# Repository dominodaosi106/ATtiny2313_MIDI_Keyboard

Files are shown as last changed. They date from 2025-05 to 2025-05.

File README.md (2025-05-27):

# ATtiny2313_MIDI_Keyboard
# MIDIコントローラ基板 取扱説明書(ver1用）

## 概要
このMIDIコントローラ基板は、ATtiny2313Aマイクロコントローラを搭載し、MIDI信号を送信して楽器やソフトウェアを制御するためのデバイスです。以下の機能を提供します：
- 12個のノートボタン（C, C#, D, D#, E, F, F#, G, G#, A, A#, B）による音階の発音
- MIDIチャンネル選択（1～16）
- オクターブシフト機能（-5～+3オクターブ）
- プログラムチェンジ（ピアノ、オルゴール、矩形波、ベース+リード）
- MIDIチャンネル10でのオクターブシフトロック機能

電源を入れると、初期設定に基づいてMIDIチャンネルと基準ノートが設定され、ボタン操作で音を鳴らしたり設定を変更したりできます。

## 操作方法

### 1. 基本操作
- **ノートボタン（C, C#, D, D#, E, F, F#, G, G#, A, A#, B）**：
  - 押す：対応する音階をMIDI信号として発音（ベロシティ127）。
  - 離す：発音開始時の音階を停止。
  - 例：Cボタンを押してC4が鳴り、オクターブシフト後に離すとC4が停止。
- **オクターブシフト（UP/DOWNボタン）**：
  - **短押し（200ms未満）**：押すと即時にオクターブが上下し、離してもシフトを維持。
  - **長押し（200ms以上）**：押すと即時にオクターブが上下し、離すと元のオクターブに戻る。
  - 範囲：-5～+3オクターブ（例：C4→C-1～C7）。
- **ファンクションキー（UP+DOWN同時押し）**：
  - UPとDOWNボタンを同時に押すと、ファンクションキーモードに移行。
  - 他のボタン（C#, D#, F#, A#, C, D, A, B）を押して各種設定を変更。
  - どちらかのボタンを離すと通常モードに戻る。

### 2. ファンクションキーモードでの操作
ファンクションキーモード（UP+DOWN同時押し）で以下の操作が可能です：
- **MIDIチャンネル変更**：
  - **C#**：MIDIチャンネル1（基準ノート：C4）に設定。
  - **D#**：MIDIチャンネル10に設定（基準ノートは現在の値を保持）。
  - **F#**：MIDIチャンネルを1つ下げる（1～16、基準ノートは保持）。
  - **A#**：MIDIチャンネルを1つ上げる（1～16、基準ノートは保持）。
- **プログラムチェンジ**：
  - **C**：プログラム1（ピアノ）に変更。
  - **D**：プログラム10（オルゴール）に変更。
  - **A**：プログラム88（ベース+リード）に変更。
  - **B**：プログラム81（矩形波）に変更。

### 3. 初期設定
- **MIDIチャンネルと基準ノート**：
  - 起動時のCHピンの状態で初期設定：
    - CHピンがLOW：MIDIチャンネル1、基準ノートC4（60）。
    - CHピンがHIGH：MIDIチャンネル10、基準ノートC2（36）。
- **オクターブシフト**：
  - 初期値は0（基準ノートそのまま）。
  - MIDIチャンネル10でMODEピンがHIGHの場合、オクターブシフトは無効（常に0）。

### 4. 注意事項
- **オクターブシフト中の発音**：
  - ノートボタンを押している間にオクターブシフトしても、発音中の音は継続。
  - ノートボタンを離すと、押した時点の音階（例：C4）が停止。
  - 新たに押したノートは現在のオクターブシフトを反映（例：C5）。
- **MIDIチャンネル変更**：
  - CH1からCH10に変更しても、現在の基準ノート（例：C4やC6）が保持される。
  - CH1への変更（C#）では基準ノートがC4にリセット。
- **MODEピン（MIDIチャンネル10）**：
  - MODEピンがHIGHの場合、オクターブシフトが無効化され、基準ノート（C2など）で固定。
- **デバウンス**：
  - ボタン操作は10msのデバウンス処理済み。素早い連打でも安定動作。
- **電源**：
  - 電源投入後、CHピンの状態を即座に読み込み。
  - MIDI機器に正しく接続してください（MIDI OUT端子を使用）。

### 5. トラブルシューティング
- **音が出ない**：
  - MIDIケーブルが正しく接続されているか確認。
  - MIDIチャンネルが受信機器と一致しているか確認（C#, D#, F#, A#で変更）。
  - プログラムチェンジが適切か確認（C, D, A, Bで変更）。
- **オクターブシフトが効かない**：
  - MIDIチャンネル10でMODEピンがHIGHでないか確認（HIGHでシフト無効）。
  - UP/DOWNボタンの短押し/長押しを試す。
- **意図しない音階が鳴る**：
  - 現在の基準ノートとオクターブシフトを確認（CH1: C4ベース、CH10: C2ベース）。
  - ファンクションキー+C#でCH1（C4）にリセット可能。

## 仕様
- **マイクロコントローラ**：ATtiny2313A（内蔵1MHzクロック）
- **ビルド環境**：Atmel Studio 7 (Version: 7.0.129)
- **MIDIボーレート**：31,250bps（標準）
- **電源**：5V（VCC-GND間）
- **ボタン**：12ノートボタン、2シフトボタン（UP/DOWN）、2設定ピン（CH, MODE）

---

ご不明点やサポートが必要な場合は、開発者にご連絡ください。

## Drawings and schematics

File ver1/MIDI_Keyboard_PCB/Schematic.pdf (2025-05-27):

GND | GND ⁺⁵V | +5V

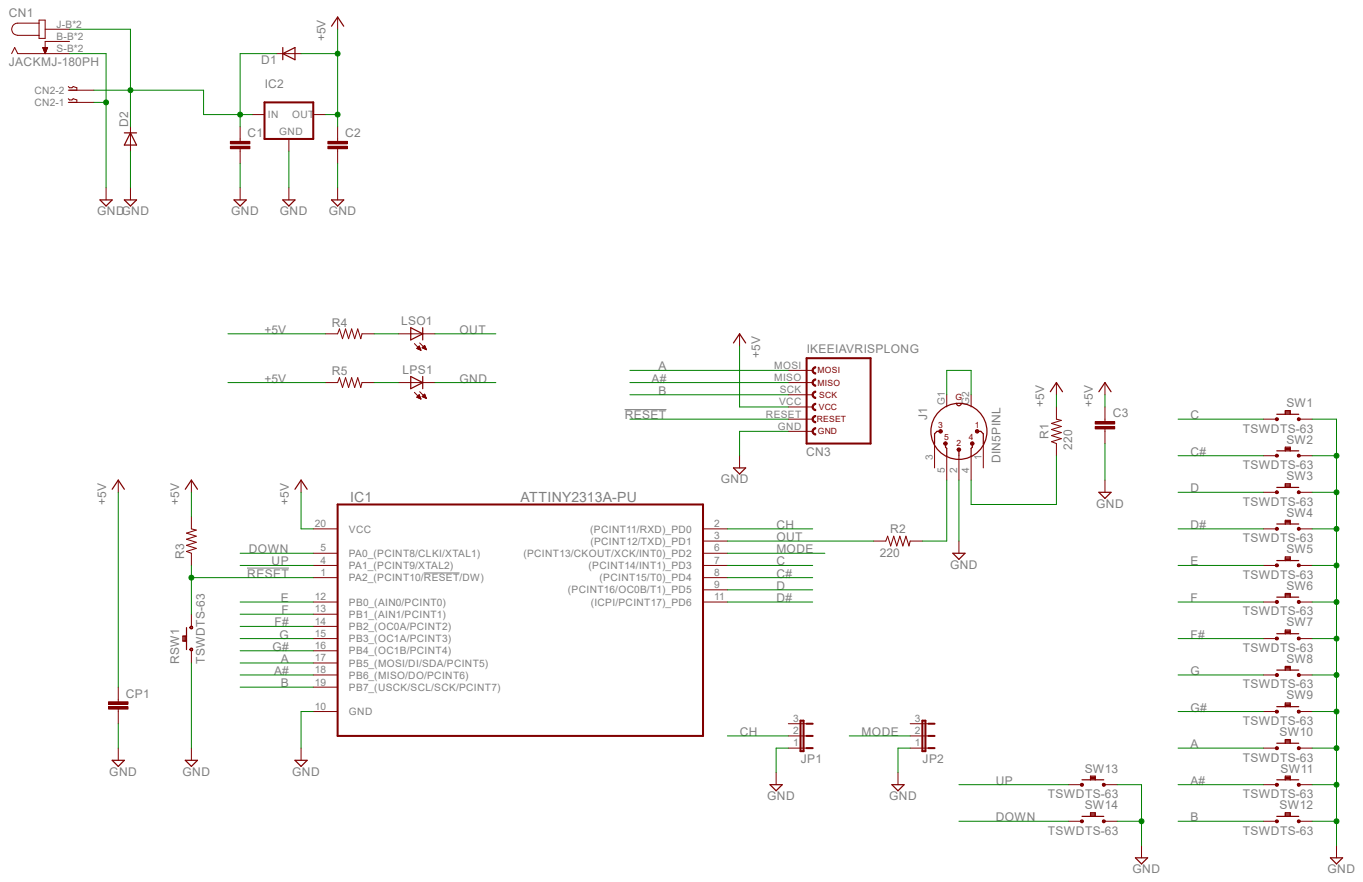
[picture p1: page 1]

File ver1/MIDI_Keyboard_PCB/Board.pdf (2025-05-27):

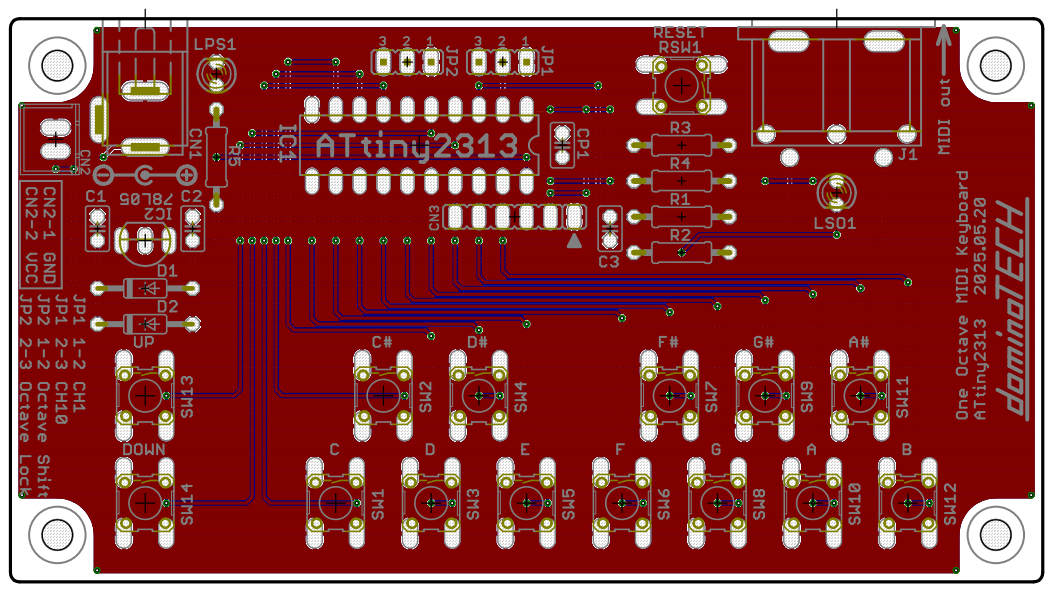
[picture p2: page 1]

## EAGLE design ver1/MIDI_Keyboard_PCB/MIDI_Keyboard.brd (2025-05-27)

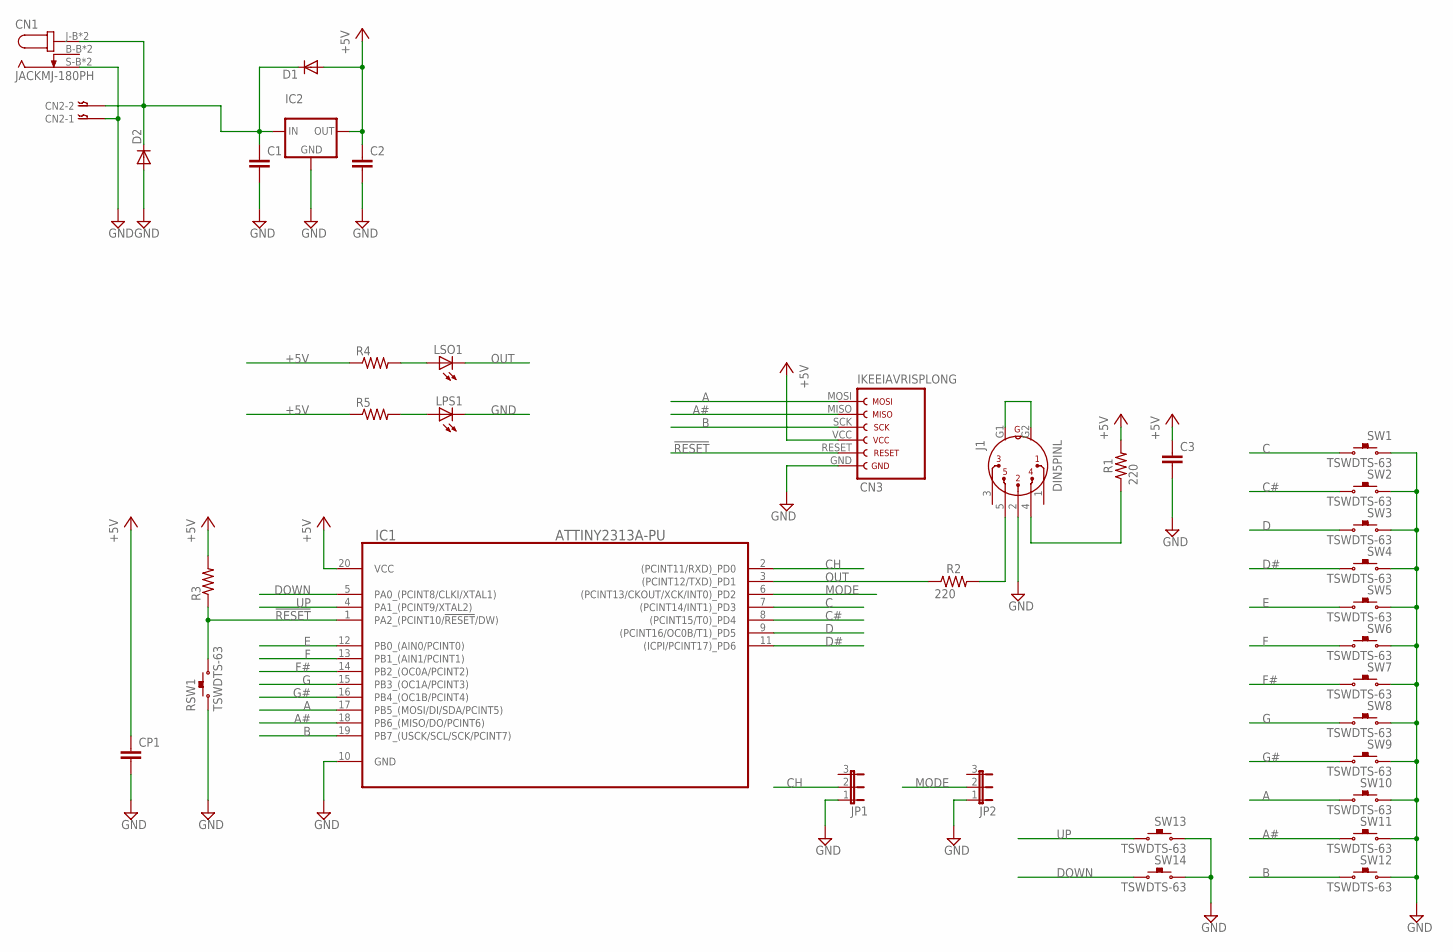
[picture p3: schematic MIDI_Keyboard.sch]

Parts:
C1, C2, C3: C-EU025-025X050; C025-025X050
CN1: JACKMJ-180PH; MJ-179PH
CN2: B2B-XH-A
CN3: IKEEIAVRISPLONG; IKEEIAVRISP
CP1: C-EU025-025X050; C025-025X050
D1, D2: 1N4148DO35-10R; DO35-10R
IC1: ATTINY2313A-PU; DIP254P762X533-20
IC2: 78LXXL; TO92LINE
J1: DIN5PINL
JP1, JP2: JP2E; JP2
LPS1: LED3MM
LSO1: LED3MM
R1, R2: 220; 0207/10
R3, R4, R5: R-US_0207/10; 0207/10
RSW1: TSWDTS-63; DTS-63
SW1, SW2, SW3, SW4, SW5, SW6, SW7, SW8, SW9, SW10, SW11, SW12, SW13, SW14: TSWDTS-63; DTS-63

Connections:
!RESET: CN3.RESET, IC1.1 (PA2_(PCINT10/!RESET!/DW)), R3.1, RSW1.1, RSW1.2 (1)
+5V: C2.1, C3.1, CN3.VCC, CP1.1, D1.A, IC1.20 (VCC), IC2.1 (OUT), R1.2, R3.2, R4.1, R5.1
A: CN3.MOSI, IC1.17 (PB5_(MOSI/DI/SDA/PCINT5)), SW10.1, SW10.2 (1)
A#: CN3.MISO, IC1.18 (PB6_(MISO/DO/PCINT6)), SW11.1, SW11.2 (1)
B: CN3.SCK, IC1.19 (PB7_(USCK/SCL/SCK/PCINT7)), SW12.1, SW12.2 (1)
C: IC1.7 ((PCINT14/INT1)_PD3), SW1.1, SW1.2 (1)
C#: IC1.8 ((PCINT15/T0)_PD4), SW2.1, SW2.2 (1)
CH: IC1.2 ((PCINT11/RXD)_PD0), JP1.2
D: IC1.9 ((PCINT16/OC0B/T1)_PD5), SW3.1, SW3.2 (1)
D#: IC1.11 ((ICPI/PCINT17)_PD6), SW4.1, SW4.2 (1)
DOWN: IC1.5 (PA0_(PCINT8/CLKI/XTAL1)), SW14.1, SW14.2 (1)
E: IC1.12 (PB0_(AIN0/PCINT0)), SW5.1, SW5.2 (1)
F: IC1.13 (PB1_(AIN1/PCINT1)), SW6.1, SW6.2 (1)
F#: IC1.14 (PB2_(OC0A/PCINT2)), SW7.1, SW7.2 (1)
G: IC1.15 (PB3_(OC1A/PCINT3)), SW8.1, SW8.2 (1)
G#: IC1.16 (PB4_(OC1B/PCINT4)), SW9.1, SW9.2 (1)
GND: C1.2, C2.2, C3.2, CN1.S-B (1), CN1.S-T (1), CN2.1, CN3.GND, CP1.2, D2.A, IC1.10 (GND), IC2.2 (GND), J1.2, JP1.1, JP2.1, LPS1.K (C), RSW1.3 (2), RSW1.4 (2), SW1.3 (2), SW1.4 (2), SW2.3 (2), SW2.4 (2), SW3.3 (2), SW3.4 (2), SW4.3 (2), SW4.4 (2), SW5.3 (2), SW5.4 (2), SW6.3 (2), SW6.4 (2), SW7.3 (2), SW7.4 (2), SW8.3 (2), SW8.4 (2), SW9.3 (2), SW9.4 (2), SW10.3 (2), SW10.4 (2), SW11.3 (2), SW11.4 (2), SW12.3 (2), SW12.4 (2), SW13.3 (2), SW13.4 (2), SW14.3 (2), SW14.4 (2)
MODE: IC1.6 ((PCINT13/CKOUT/XCK/INT0)_PD2), JP2.2
unnamed: J1.4, R1.1
unnamed: J1.5, R2.2
unnamed: J1.G1, J1.G2
unnamed: LSO1.A, R4.2
unnamed: LPS1.A, R5.2
unnamed: C1.1, CN1.J-B (3), CN1.J-T (3), CN2.2, D1.C, D2.C, IC2.3 (IN)
OUT: IC1.3 ((PCINT12/TXD)_PD1), LSO1.K (C), R2.1
UP: IC1.4 (PA1_(PCINT9/XTAL2)), SW13.1, SW13.2 (1)

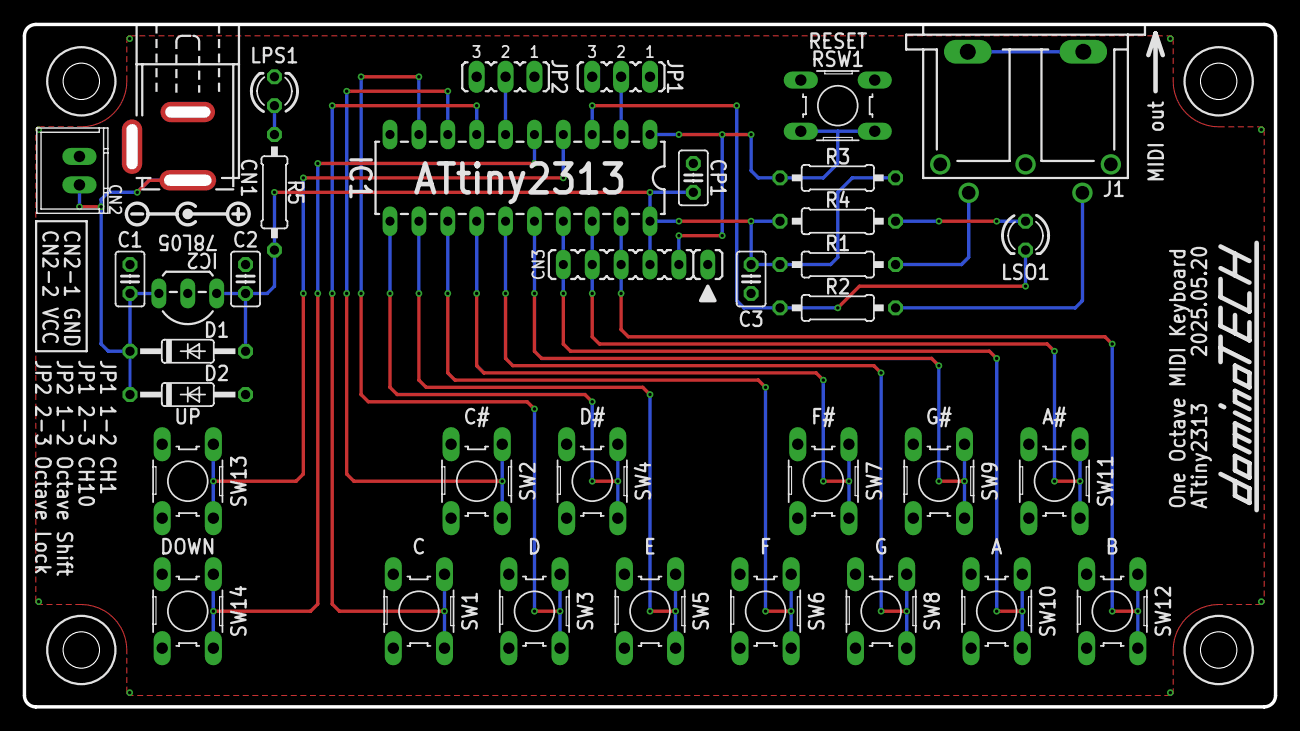
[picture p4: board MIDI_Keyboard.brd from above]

Board: 2 copper layers, 110.0 x 60.0 mm, 36 parts (0 on the bottom side), 26 nets.

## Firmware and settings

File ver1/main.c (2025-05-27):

/*
 * 【ポート対応】 ATtiny2313A
 * x: 存在しない, -: 空き
 * bit       7     6     5     4     3     2     1     0
 * portA     x     x     x     x     x     x     UP    DOWN
 * portB     B     A#    A     G#    G     F#    F     E
 * portD     x     D#    D     C#    C     MODE  MIDI  CH
 *
 * 【ATtiny2313Aピンマッピング】
 *   (RESET) PA2 |1       20| VCC
 *     (CH) PD0 |2       19| PB7 (B)
 *   (MIDI) PD1 |3       18| PB6 (A#)
 *     (UP) PA1 |4       17| PB5 (A)
 *   (DOWN) PA0 |5       16| PB4 (G#)
 *   (MODE) PD2 |6       15| PB3 (G)
 *      (C) PD3 |7       14| PB2 (F#)
 *     (C#) PD4 |8       13| PB1 (F)
 *      (D) PD5 |9       12| PB0 (E)
 *      GND     |10      11| PD6 (D#)
 * ※MODE, CH (内部プルアップ)
 *
 * 【ビルド環境】
 * Atmel Studio 7 (Version: 7.0.129)
 * ATtiny2313A 内蔵1MHzクロック
 */



#define F_CPU 1000000UL // ATtiny2313のクロック速度、1MHz

#include <avr/io.h>
#include <util/delay.h>

// ピンの状態を追跡するためのグローバル変数
uint8_t prev_state_portd = 0xFF; // PORTDの前の状態
uint8_t prev_state_portb = 0xFF; // PORTBの前の状態
uint8_t midi_channel = 0; // MIDIチャンネル（0=CH1, ..., 15=CH16）
uint8_t base_note = 60; // 基準ノート番号（初期: 60=C4, CH10=36=C2）
int8_t octave_shift = 0; // オクターブシフト（全チャンネル: -5～+3）
uint8_t active_notes[12] = {0}; // アクティブノート（0=オフ, 1=オン、PD3-PD6=0-3, PB0-PB7=4-11）
int8_t note_octave_shifts[12] = {0}; // 各ノートの発音時のoctave_shift値

void uart_init(void) {
	UBRRH = 0;
	UBRRL = (F_CPU / (16UL * 31250)) - 1; // 31,250bps（MIDI標準）
	UCSRB = (1 << TXEN); // 送信許可
	UCSRC = (1 << UCSZ1) | (1 << UCSZ0); // 8ビットデータフォーマット
}

void uart_transmit(unsigned char data) {
	while (!(UCSRA & (1 << UDRE))); // データレジスタが空くまで待つ
	UDR = data; // データを送信
}

void midi_note_on(unsigned char channel, unsigned char note, unsigned char velocity) {
	uart_transmit(0x90 | channel);
	uart_transmit(note);
	uart_transmit(velocity);
}

void midi_note_off(unsigned char channel, unsigned char note) {
	uart_transmit(0x80 | channel);
	uart_transmit(note);
	uart_transmit(0);
}

void midi_program_change(uint8_t channel, uint8_t program) {
	uart_transmit(0xC0 | channel);
	uart_transmit(program);
}

void init_settings(void) {
	// PD0でMIDIチャンネル設定（LOW=CH1, HIGH=CH10）
	if (!(PIND & (1 << PD0))) {
		midi_channel = 0; // CH1
		base_note = 60; // C4
		} else {
		midi_channel = 9; // CH10
		base_note = 36; // C2
	}
}

void update_octave(void) {
	static uint8_t last_pa1 = 1, last_pa0 = 1; // PA1, PA0の前回状態
	static uint8_t pa1_pressed = 0, pa0_pressed = 0; // ボタン押下フラグ
	static uint16_t pa1_timer = 0, pa0_timer = 0; // 押下時間計測
	static int8_t original_shift = 0; // 押す前のオクターブシフト値
	static uint8_t function_mode = 0; // ファンクションキーモードフラグ
	uint8_t curr_pa1 = PINA & (1 << PA1) ? 1 : 0; // 現在のPA1状態
	uint8_t curr_pa0 = PINA & (1 << PA0) ? 1 : 0; // 現在のPA0状態
	uint8_t curr_state_portd = PIND;
	uint8_t curr_state_portb = PINB;

	// チャンネル10かつPD2=HIGHの場合、オクターブシフト無効
	if (midi_channel == 9 && (PIND & (1 << PD2))) {
		if (octave_shift != 0) {
			octave_shift = 0; // シフトをリセット
		}
		last_pa1 = curr_pa1;
		last_pa0 = curr_pa0;
		pa1_pressed = 0;
		pa0_pressed = 0;
		pa1_timer = 0;
		pa0_timer = 0;
		function_mode = 0;
		return; // PA1/PA0の入力を無視
	}

	// ファンクションキー（PA1+PA0同時押し）の検出
	if (!curr_pa1 && !curr_pa0 && (last_pa1 || last_pa0)) { // 両方押された
		function_mode = 1; // ファンクションキーモードON
		pa1_pressed = 0;
		pa0_pressed = 0;
		pa1_timer = 0;
		pa0_timer = 0;
		_delay_ms(10); // デバウンス
		} else if (function_mode && (curr_pa1 || curr_pa0)) { // どちらかが離された
		function_mode = 0; // ファンクションキーモードOFF
		_delay_ms(10); // デバウンス
	}

	if (function_mode) {
		// ファンクションキー+C#（PD4）：MIDI CH1
		if (!(curr_state_portd & (1 << PD4)) && (prev_state_portd & (1 << PD4))) {
			midi_channel = 0;
			base_note = 60; // C4（明示的に設定）
			_delay_ms(10);
		}
		// ファンクションキー+D#（PD6）：MIDI CH10
		if (!(curr_state_portd & (1 << PD6)) && (prev_state_portd & (1 << PD6))) {
			midi_channel = 9;
			// base_noteは保持
			_delay_ms(10);
		}
		// ファンクションキー+F#（PB2）：MIDI CH-
		if (!(curr_state_portb & (1 << PB2)) && (prev_state_portb & (1 << PB2))) {
			if (midi_channel > 0) {
				midi_channel--; // 1～16（0～15）
				// base_noteは保持
			}
			_delay_ms(10);
		}
		// ファンクションキー+A#（PB6）：MIDI CH+
		if (!(curr_state_portb & (1 << PB6)) && (prev_state_portb & (1 << PB6))) {
			if (midi_channel < 15) {
				midi_channel++; // 1～16（0～15）
				// base_noteは保持
			}
			_delay_ms(10);
		}
		// ファンクションキー+C（PD3）：プログラムチェンジ1（ピアノ）
		if (!(curr_state_portd & (1 << PD3)) && (prev_state_portd & (1 << PD3))) {
			midi_program_change(midi_channel, 0); // ピアノ
			_delay_ms(10);
		}
		// ファンクションキー+D（PD5）：プログラムチェンジ10（オルゴール）
		if (!(curr_state_portd & (1 << PD5)) && (prev_state_portd & (1 << PD5))) {
			midi_program_change(midi_channel, 10); // オルゴール
			_delay_ms(10);
		}
		// ファンクションキー+A（PB5）：プログラムチェンジ88（ベース+リード）
		if (!(curr_state_portb & (1 << PB5)) && (prev_state_portb & (1 << PB5))) {
			midi_program_change(midi_channel, 87); // ベース+リード
			_delay_ms(10);
		}
		// ファンクションキー+B（PB7）：プログラムチェンジ81（矩形波）
		if (!(curr_state_portb & (1 << PB7)) && (prev_state_portb & (1 << PB7))) {
			midi_program_change(midi_channel, 80); // 矩形波
			_delay_ms(10);
		}
		last_pa1 = curr_pa1;
		last_pa0 = curr_pa0;
		return; // ファンクションキーモード中は通常のシフト処理をスキップ
	}

	// PA1（オクターブアップ）の処理
	if (!curr_pa1 && last_pa1) { // PA1が押された（立ち下がり）
		pa1_pressed = 1;
		pa1_timer = 0; // タイマーリセット
		original_shift = octave_shift; // 現在のシフト値を保存
		if (octave_shift < 3) { // 全チャンネルで-5～+3
			octave_shift++; // 即時シフトアップ
		}
		} else if (curr_pa1 && !last_pa1 && pa1_pressed) { // PA1が離された
		if (pa1_timer >= 200) { // 長押し（200ms以上）
			octave_shift = original_shift; // 元のシフト値に戻す
		} // 短押し（200ms未満）の場合はシフトを維持
		pa1_pressed = 0; // 押下フラグクリア
		} else if (pa1_pressed) { // PA1が押され続けている
		pa1_timer += 10; // 10msごとにタイマー増加
	}

	// PA0（オクターブダウン）の処理
	if (!curr_pa0 && last_pa0) { // PA0が押された（立ち下がり）
		pa0_pressed = 1;
		pa0_timer = 0; // タイマーリセット
		original_shift = octave_shift; // 現在のシフト値を保存
		if (octave_shift > -5) { // 全チャンネルで-5～+3
			octave_shift--; // 即時シフトダウン
		}
		} else if (curr_pa0 && !last_pa0 && pa0_pressed) { // PA0が離された
		if (pa0_timer >= 200) { // 長押し（200ms以上）
			octave_shift = original_shift; // 元のシフト値に戻す
		} // 短押し（200ms未満）の場合はシフトを維持
		pa0_pressed = 0; // 押下フラグクリア
		} else if (pa0_pressed) { // PA0が押され続けている
		pa0_timer += 10; // 10msごとにタイマー増加
	}

	last_pa1 = curr_pa1;
	last_pa0 = curr_pa0;
}

void check_pin_changes(void) {
	uint8_t curr_state_portd = PIND;
	uint8_t curr_state_portb = PINB;

	// PORTD（PD3-PD6）
	for (uint8_t i = 3; i <= 6; i++) {
		uint8_t mask = (1 << i);
		uint8_t index = i - 3; // active_notesのインデックス
		int16_t note = base_note + (i - 3) + (octave_shift * 12); // 現在のノート計算
		int16_t note_at_press = base_note + (i - 3) + (note_octave_shifts[index] * 12); // 押した時点のノート
		if (note >= 0 && note <= 127) { // MIDIノート範囲チェック
			if (!(curr_state_portd & mask) && (prev_state_portd & mask)) {
				midi_note_on(midi_channel, note, 127);
				active_notes[index] = 1; // ノートオン状態を記録
				note_octave_shifts[index] = octave_shift; // 発音時のoctave_shiftを記録
				} else if ((curr_state_portd & mask) && !(prev_state_portd & mask) && active_notes[index]) {
				midi_note_off(midi_channel, note_at_press); // 押した時点のノートをオフ
				active_notes[index] = 0; // ノートオフ状態をクリア
			}
		}
	}

	// PORTB（PB0-PB7）
	for (uint8_t i = 0; i <= 7; i++) {
		uint8_t mask = (1 << i);
		uint8_t index = 4 + i; // active_notesのインデックス
		int16_t note = base_note + 4 + i + (octave_shift * 12); // 現在のノート計算
		int16_t note_at_press = base_note + 4 + i + (note_octave_shifts[index] * 12); // 押した時点のノート
		if (note >= 0 && note <= 127) {
			if (!(curr_state_portb & mask) && (prev_state_portb & mask)) {
				midi_note_on(midi_channel, note, 127);
				active_notes[index] = 1; // ノートオン状態を記録
				note_octave_shifts[index] = octave_shift; // 発音時のoctave_shiftを記録
				} else if ((curr_state_portb & mask) && !(prev_state_portb & mask) && active_notes[index]) {
				midi_note_off(midi_channel, note_at_press); // 押した時点のノートをオフ
				active_notes[index] = 0; // ノートオフ状態をクリア
			}
		}
	}

	prev_state_portd = curr_state_portd;
	prev_state_portb = curr_state_portb;
}

int main(void) {
	// ピンを入力に設定
	DDRA &= ~((1 << PA0) | (1 << PA1)); // PA0, PA1を入力
	DDRD &= ~((1 << PD0) | (1 << PD2) | (1 << PD3) | (1 << PD4) | (1 << PD5) | (1 << PD6)); // PD0, PD2-PD6
	DDRB &= ~((1 << PB0) | (1 << PB1) | (1 << PB2) | (1 << PB3) |
	(1 << PB4) | (1 << PB5) | (1 << PB6) | (1 << PB7)); // PB0-PB7

	// プルアップ抵抗を有効化
	PORTA |= ((1 << PA0) | (1 << PA1));
	PORTD |= ((1 << PD0) | (1 << PD2) | (1 << PD3) | (1 << PD4) | (1 << PD5) | (1 << PD6));
	PORTB |= ((1 << PB0) | (1 << PB1) | (1 << PB2) | (1 << PB3) |
	(1 << PB4) | (1 << PB5) | (1 << PB6) | (1 << PB7));

	uart_init();
	init_settings(); // 起動時にPD0を読み込み

	while (1) {
		update_octave(); // オクターブシフトおよびファンクションキー処理
		check_pin_changes(); // ピンの状態チェック
		_delay_ms(10); // デバウンス
	}
}

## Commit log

2025-05-27 main.c readme追加
2025-05-27 README更新
2025-05-27 回路図,基板データ追加
    [MIDI_Keyboard.brd, MIDI_Keyboard.sch]
2025-05-27 hex追加
2025-05-27 main.c変更
